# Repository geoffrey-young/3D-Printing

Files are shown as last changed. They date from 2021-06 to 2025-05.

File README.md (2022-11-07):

# random 3D printing stuff

### voron stuff

#### `artie v2.1650` stuff

* [2.4 mods, etc](./models/voron/2.4/)
* [superslicer profile and scripts](./superslicer/voron/2.4/)
* [klipper config and macros](./klipper/voron/)

#### `ernie vs.428` stuff

* [switchwire mods, etc](./models/voron/enderwire)

#### ercf stuff

* [ercf buffer, mounts, etc](./models/voron/ercf)

### ender stuff

* [cura profiles and start/end gcode](./cura/ender-3-v2/)
* [cura profile I used to print my Voron ABS parts](./cura/ender-3-v2/profiles/ABS-voron-parts.curaprofile)

### models

* [thingiverse](https://www.thingiverse.com/geoffreyyoung/designs)
* [voron printer mods](https://github.com/VoronDesign/VoronUsers/tree/master/printer_mods/geoffreyyoung)

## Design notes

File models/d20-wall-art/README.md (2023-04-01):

# D20 Wall Art

https://www.thingiverse.com/thing:4802682
**By [Geoffrey Young](https://www.thingiverse.com/geoffreyyoung)**

## Summary

### v2

Updates on 2023-04-01:

- Minor model updates, including edge tidying, bottom bevels, and a bit less plastic.
- Models are now multi-material friendly, with three parts: bottom, base, and number.  You can see the parts in the silver/black/red model picture.
- Added a first pass at a base.

The silver/black/red v2 model was printed in ABS.

### v1

Some wall art for all the DnD fans out there, including my daughter.

If you use the provided guides for spacing the end product is about 15" x 15" (38cm x 38cm). 

I used Protopasta's Iron-filled Metal Composite PLA

https://www.proto-pasta.com/collections/metal-filled/products/magnetic-iron-pla

and rusted the pieces before sanding and polishing the tops.  A light coat of spray polyurethane was added so the rust doesn't come off on finger or the wall, but I'm honestly not sure if I like the way the coating looks (they were pretty cool looking with the rust showing, while the finish makes it look kind of painted on).

3M Command strips were used for mounting.

Have fun!

#### v1 Print Settings

At full size, this required a full 1kg of iron-filled filament (that is, two 500g spools used thoughtfully to minimize spool leftovers) at the following settings:

 - Rafts      :  No                   
 - Supports   :  No                   
 - Nozzle     :  0.6mm                
 - Resolution :  0.2                
 - Line Width :  0.5                 
 - Infill     :  20% with 1 infill step
 - Bottom     :  4 layers
 - Top        :  8 layers
 - Walls      :  3

You can find instructions for rusting the iron filament here:

https://www.proto-pasta.com/blogs/how-to/17590348-improved-rusting-method-for-iron-prints

I used saturated salt in vinegar with added peroxide in a heated area over the course of a week.  After the final sanding I sprayed with just peroxide and let them sit overnight, which added a layer of rust to the sanded areas that I polished off using a cloth wheel.  ymmv :)

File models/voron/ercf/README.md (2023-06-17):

# ercf stuff...

| | |
| :--- | :--- |
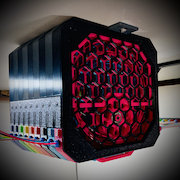
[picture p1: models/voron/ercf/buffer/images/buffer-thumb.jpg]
buffer (https://github.com/geoffrey-young/pika-filament-buffer)
| piKa filament buffer ([now a standalone repo](https://github.com/geoffrey-young/pika-filament-buffer)) |  |
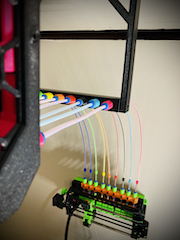
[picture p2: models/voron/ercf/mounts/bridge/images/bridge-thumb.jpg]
magnet bridge
| magnet bridge |  |
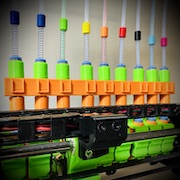
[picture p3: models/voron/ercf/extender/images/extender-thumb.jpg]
extender
| 90 degree extender |  |
| upside-down tag plates | numbers  |
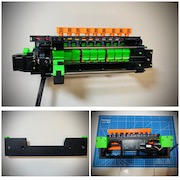
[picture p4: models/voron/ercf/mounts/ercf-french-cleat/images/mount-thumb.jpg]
mount
| french cleat mount |  |
| sb lgx mount with filament sensor<br>(no longer required with sensorless ercf) | [stl here](../stealthburner/stl/lgx/cw2/sb-lgx-cw2-ercf-v5.stl) |
| random ercf odds and ends | [here](./random/) |

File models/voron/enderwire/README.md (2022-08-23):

# `ernie vs.428`, the steathbowden enderwire

*an e3v2 switchwire conversion...*

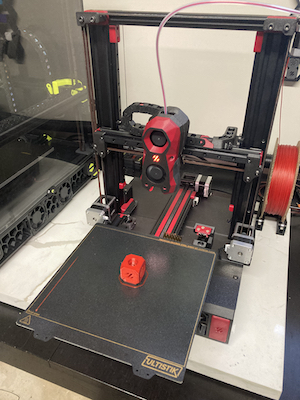
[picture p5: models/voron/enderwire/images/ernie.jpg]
ernie


### why?

this is a Voron Switchwire build for an Ender 3 v2, based on the popular [DaRk_dOg](https://github.com/boubounokefalos/Ender_SW) Switchwire mod.

the [DaRk_dOg](https://github.com/boubounokefalos/Ender_SW) mod is really fantastic, and deserves a ton of credit.  it does have some limitations, however - namely that I wanted auto z, which required a homing switch and klicky probe to be fit in somewhere.  

other than auto z, my other goal was to use as many of the original e3v2 parts as I could, in order to keep conversion costs as low as possible.

the result is `ernie vs.428` - a bowden-based stealthburner switchwire using the original e3v2 extruder, creality 4.2.2 board, and whatever other parts I could salvage from the parent e3v2.

### BOM

major BOM changes from the official [Voron Switchwire](https://vorondesign.com/voron_switchwire) and/or [DaRk_dOg](https://github.com/boubounokefalos/Ender_SW/wiki/Custom-Bom) BOM are:

| | | |
| :--- | :--- | :--- |
| **350mm rails** | 2 | provide room for the homing switch and klicky dock, and replace the dual 300mm Y rails in the DaRk_dOg mod |
| **250mm 2020 extrusions** | 2 | for use as both a bed mount and to add length for the homing switch and klicky mount.  I ordered mine from aliexpress [here](https://www.aliexpress.com/item/2255799859462895.html) |
| **m5x60 SHCS**| 2 | 8 were already needed for the frame front.  the 2 you have leftover from your pack of 10 will be used for the y idler |
| **extra GT2 belt** | 100mm | I ordered 4000mm of GT2 belt and it was more than enough, but the y axis probably needs 80-100mm more belt than a standard ender conversion.  I haven't measured the difference between the stock Switchwire (Prusa-based) BOM lengths and an ender conversion to know for sure. |
| **m4 FHCS and extrusion nuts** | 4 | to mount the bed on the extrusion.  you can probably use m3 flat heads if you have them. |
| **aliexpress [door puller](https://www.aliexpress.com/item/2255801159810332.html)** | 1 | $3 alternative to the $20 keybak from the sourcing guide, recommended on discord.  note there are 500g, 800g, and 1.1kg versions.  I have the 500g but it seems the 800g is the preferred tension.  ymmv. |
| **m5 tap** | 1 | this isn't specific to my mod - most of my stock e3v2 4040 frame was *not* tapped, so the screws for the DaRk_dOg grills had no place to go.  you'll be very happy you have this when the time comes. |

I didn't keep track of all the screws and fasteners I used, since I had an abundance sitting around, but there was nothing unique required other than the m4 screws and nuts, which I don't think are part of other standard Voron BOMs.

all the rest is from my stripped down ender...

### changes, mods, etc

there are a few categories of changes:

- alterations required where fit for my october 2020 e3v2 was a bit different than the DaRk_dOg model
- new parts needed for klicky auto z calibration
- bowden mod for stealthburner

#### replacement parts

| | |
| :--- | :--- |
| [`[a]_xz_cable_cover.stl`](stl/replacements/[a]_xz_cable_cover.stl)| a shorter cable cover so the fit against the z block is tight |
| [`[a]_y_axis_ls_mount.stl`](stl/replacements/[a]_y_axis_ls_mount.stl)| stubby y endstop mount to fit behind the 350mm rail |
| [`cover_4040_extrusion_cut_enderV2.stl`](stl/replacements/cover_4040_extrusion_cut_enderV2.stl)| the factory cutout in my frame for the electronics cable was extra large it seems |
| [`grill_rear_middle.stl`](stl/replacements/grill_rear_middle.stl)| modified to fit the factory power inlet and switch |
| [`grill_rear_right.stl`](stl/replacements/grill_rear_right.stl)| put some heatsets in the 6020 fan and use m3 screws from behind to hold it in place |
| [`keybak_gantry_anchor.stl`](stl/replacements/keybak_gantry_anchor.stl)| specific to the aliexpress door pull |
| [`keybak_idler_bracket.stl`](stl/replacements/keybak_idler_bracket.stl)| repurpose bearings, screw, and heatset from one of the ender tensioners.  there are some m4 washers you can use on the outside, but standard m5 shims work well. |
| [`keybak_mount.stl`](stl/replacements/keybak_mount.stl)| specific to the aliexpress door pull |

#### new parts

| | |
| :--- | :--- |
| [`amplifier-foot-mount.stl`](stl/new/amplifier-foot-mount.stl)| mount for standard v2.4r2/trident amplifier feet |
| [`brush-mount.stl`](stl/new/brush-mount.stl)| if you want a brush |
| [`extruder-inlet.stl`](stl/new/extruder-inlet.stl)| so you can run a 4x3mm bowden tube from the filament sensor to the extruder |
| [`extruder-knob.stl`](stl/new/extruder-knob.stl)| repurpose the large heatset from the stock extruder knob for this.  can be printed in 2 colors following the v0 miniburner process outlined [here](https://imgur.com/a/FDyniIr) |
| [`extruder-mount.stl`](stl/new/extruder-mount.stl)| mount for the stock ender extruder and stepper |
| [`klicky-mount.stl`](stl/new/klicky-mount.stl)| for auto z.  I use a m3x4mm screw in place of a magnet so I can adjust the connection strength |
| [`m4-standoff-2mm.stl`](stl/new/m4-standoff-2mm.stl)| heat and height buffer between the bed and extrusions |
| [`nozzle_probe.stl`](https://github.com/VoronDesign/Voron-2/blob/Voron2.4/STLs/Z_Endstop/nozzle_probe.stl)| use the V2.4 standard z nozzle probe assembly |
| [`stealthbowden-body.stl`](stl/new/stealthbowden-body.stl) | bowden stealthburner requires one of these two adapters from the [`Voron-Afterburner`](https://github.com/VoronDesign/Voron-Afterburner/tree/be5034975cd70203ea97729bf2bf96b6eebf6d7f/STLs/Bowden) repo:|
| [`stealthbowden-plate.stl`](stl/new/stealthbowden-plate.stl)| [BSP adapter](https://github.com/VoronDesign/Voron-Afterburner/blob/be5034975cd70203ea97729bf2bf96b6eebf6d7f/STLs/Bowden/bowden_single_bsp_adapter.stl) or [TL collet](https://github.com/VoronDesign/Voron-Afterburner/blob/be5034975cd70203ea97729bf2bf96b6eebf6d7f/STLs/Bowden/bowden_single_tl_collet_adapter.stl)  |
| [`tl-filament-sensor-bracket.stl`](stl/new/tl-filament-sensor-bracket.stl)| trianglelabs filament runout bracket |
| [`wago-bed-mount.stl`](stl/new/wago-bed-mount.stl)| holds two wago 221-413 lever-nuts for the bed heater wires |
| [`xy_chain_end-inner.stl`](stl/new/xy_chain_end-inner.stl) | 2 hole chain end for the x axis extrusion mount point.  lets you print some bling, plus if you use it you know your chain is facing the right direction :) |
| [`y-axis-350mm-extension.stl`](stl/new/y-axis-350mm-extension.stl)| add-on to the 4040 y frame to give room for the 350mm rails.  use two m5x60 for the bottom (y idler) holes and two m5x45 or m5x50 for the hidden (upper) holes |
| [`y-bed-chain-extension-generic.stl`](stl/new/y-bed-chain-extension-generic.stl)| the longer y movement needs longer bed chains.  you can either use this extension, or take 3 links from the x chain (since it's too long anyway) |
| [`y-endstop-bed-extension.stl`](stl/new/y-endstop-bed-extension.stl)| needed to hit the new y endstop position |

#### other stuff

| | |
| :--- | :--- |
| [v-slot covers](https://www.thingiverse.com/thing:4681157)| I like these from thingiverse best |
| [2020 endcap](stl/new/2020-endcap.stl)| 2-sided mod of [this from thingiverse](https://www.thingiverse.com/thing:813368) |

### build notes, etc

the [DaRk_dOg](https://github.com/boubounokefalos/Ender_SW) mod makes the auto z mods pretty simple - it's really just another (slightly modified) 4040 extension block, longer y rails, and a few mounts.  the biggest drawback I've noticed so far is that the way I set it up you lose the adjustment screws so you need to live with a fixed bed.  klicky takes care of that for the most part (my first, untuned mesh had a 0.9mm deviation - not great, but...).  however, I think that could be worked around by just a bit more modding of the bed carriage.  stay tuned for v2 :)

here are some random build notes and other thoughts.  I'll keep adding details as I think of them...

- I don't think gear pullers are required - my e3v2 x and y motor gears aligned perfectly with the DaRk_dOg x and z assemblies.
- not all of the extrusion holes are tapped, so that m5 tap really will come in handy
- more to come...

### wiring

the wiring for the creality 4.2.2 board is well documented, but I'll eventually post my klipper config.

as for the stealthburner led and klicky wiring, both can be serviced by the bltouch port:

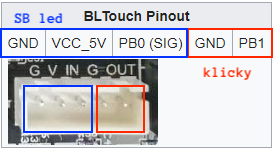
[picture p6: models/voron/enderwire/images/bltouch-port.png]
stealthburner led and klicky ports


### pictures

first print off the block - no input shaper, pressure advance, etc.  not perfect, but not bad :)

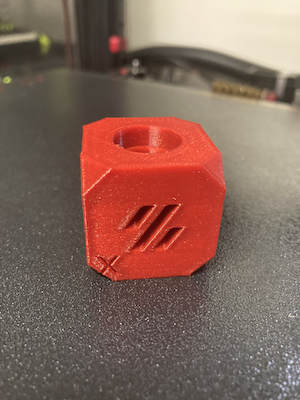
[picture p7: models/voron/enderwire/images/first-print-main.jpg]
first print


some others for reference...

| | | |
| :--- | :--- | :--- |
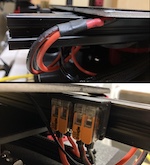
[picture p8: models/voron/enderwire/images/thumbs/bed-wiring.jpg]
bed wiring
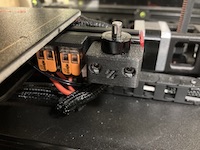
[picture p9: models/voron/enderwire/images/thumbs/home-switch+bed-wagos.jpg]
home switch and bed wagos
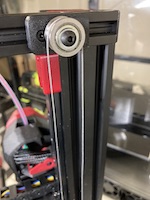
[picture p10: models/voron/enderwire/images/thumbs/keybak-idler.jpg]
keybak idler
|  |  |  |
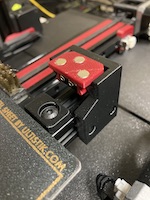
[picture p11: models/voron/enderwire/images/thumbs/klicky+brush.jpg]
klicky and brush mounts
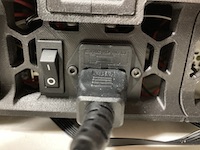
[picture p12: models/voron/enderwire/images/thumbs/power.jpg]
power inlet
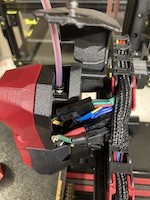
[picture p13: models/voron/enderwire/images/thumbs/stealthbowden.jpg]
stealthbowden
|  |  |  |
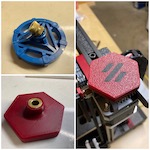
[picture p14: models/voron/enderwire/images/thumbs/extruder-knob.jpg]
extruder knob
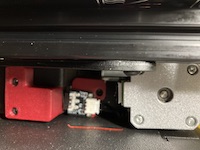
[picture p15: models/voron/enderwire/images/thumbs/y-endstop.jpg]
y endstop and bed extension
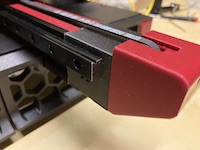
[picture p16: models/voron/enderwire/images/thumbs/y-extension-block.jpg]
y extension block
|  |  |  |
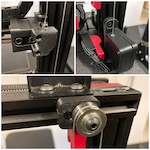
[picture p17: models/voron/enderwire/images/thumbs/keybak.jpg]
keybak
|  | |

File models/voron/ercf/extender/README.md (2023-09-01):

# ercf extender

now in 9.5mm and 10mm magnet versions.  please see [a note on magnets](https://github.com/geoffrey-young/pika-filament-buffer#a-note-on-magnets)

| | |
| :---: | :---: |
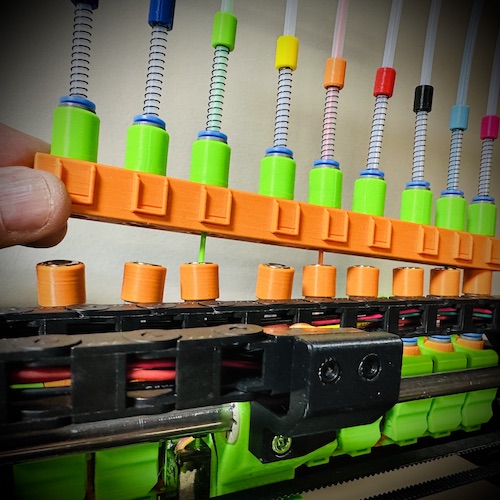
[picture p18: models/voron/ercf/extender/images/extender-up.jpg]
ercf 90 degree extender up
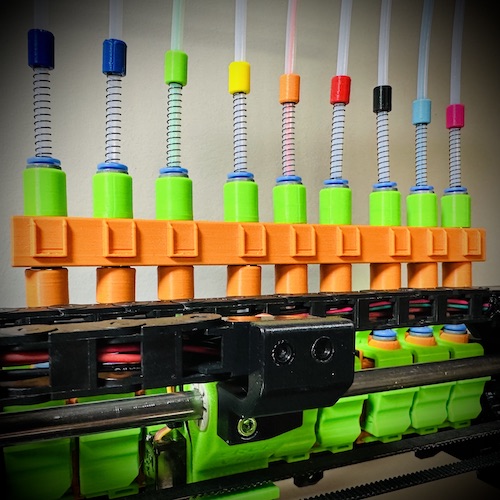
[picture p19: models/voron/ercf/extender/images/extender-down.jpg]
ercf 90 degree extender
|  |  |

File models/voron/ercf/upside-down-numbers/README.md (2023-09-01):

# ercf upside-down number tags

helpful if you happen to mount things in odd ways.  multi-material ready.

in [anonymous pro](https://www.marksimonson.com/fonts/view/anonymous-pro).  obviously.

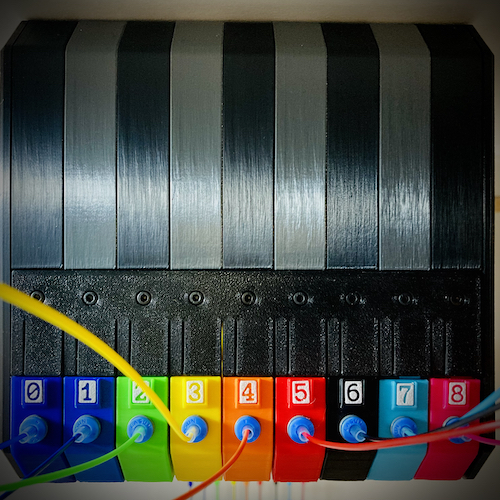
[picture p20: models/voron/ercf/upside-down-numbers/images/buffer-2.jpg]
upside down tag plates


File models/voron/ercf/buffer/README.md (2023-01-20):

# I've moved!

you can find the standalone repo [here](https://github.com/geoffrey-young/filament-buffer)

enjoy.

| | |
| :---: | :---: |
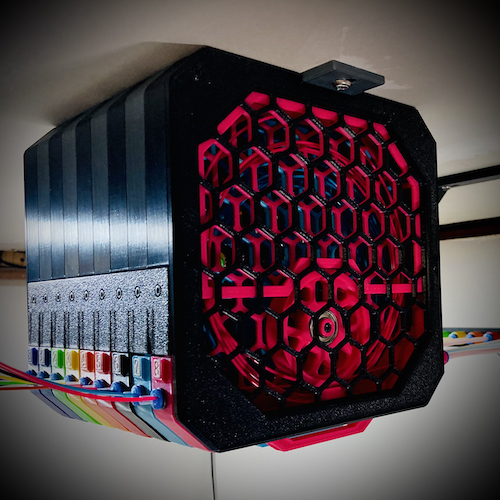
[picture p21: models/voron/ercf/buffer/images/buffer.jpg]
buffer
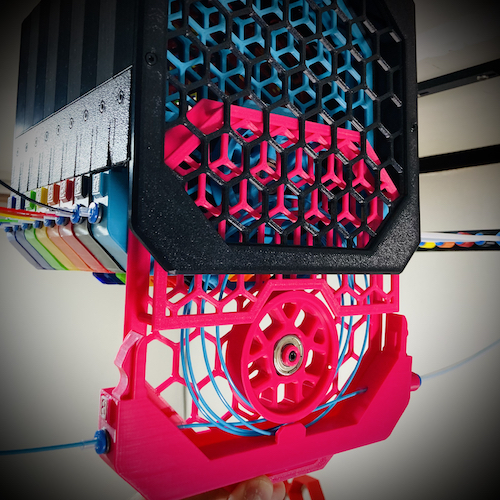
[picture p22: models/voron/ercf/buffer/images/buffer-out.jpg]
buffer out
|  |  |

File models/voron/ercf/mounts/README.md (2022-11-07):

# ercf mounts...

| | |
| :--- | :--- |
| magnet bridge | magnet bridge |
| french cleat mount | mount |

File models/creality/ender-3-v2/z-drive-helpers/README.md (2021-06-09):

# Z-Axis Motor Mount and Leveling Kit for Ender 3 V2

https://www.thingiverse.com/thing:4789170
**By [Geoffrey Young](https://www.thingiverse.com/geoffreyyoung)**

### Summary

I purchased a dual z-axis upgrade kit and the product had some tolerance issues - the z-axis mount wasn't square and the stator housing exceeded the width of the end caps.  The net result was a complete inability to mount the stepper motor square and align things properly.

This is an entire kit of mounts and tools to remedy those issues, including:

  o A simple z-axis motor mount with a bit more clearance so that the motor doesn't quite touch the z-axis rails

  o A set of adjustable leveling brackets for the other side of the stepper motor

  o A combined mount + leveling bracket (as an alternative to using separate parts)

  o Some simple washers to account for the distance difference in the x-axis roller bracket assembly

  o An adjustable spacer measuring jig for the z-axis rod lead screw

  o A simple x-axis rail level

The stepper motor leveling brackets require some hardware:

  o 2 M3x6 screws
  o 2 M3x16 screws
  o 2 M3x6x10 threaded inserts

You can see in the photos how it's all set up, but it's pretty self explanatory.  You can use the mount+bracket combo if you're adding a new stepper motor, or just add the outer leveling bracket if you want to use existing mounts.

The spacer jig is really handy, and I use the x-axis level all the time.

I'm particularly fond of the bottom bracket, which I consistenly refer to as the TRON Recognizer.

I used https://www.thingiverse.com/thing:4699747 as the base for the design, but pretty much tore it apart.  The concept for the leveling brackets were inspired by https://www.thingiverse.com/thing:4073953, which is a great idea but had too many nuts and bolts for me :)

Anyway, all these things helped me tune the upgrade kit, and I ended up applying it to the original setup as well.  Smooth as silk now.

As always, ymmv.

### Attributions

[Ender 3 / Pro / V2 Z axis motor mount](https://www.thingiverse.com/thing:4699747) by [mknet](https://www.thingiverse.com/mknet)

[Ender 3 Z-Axis Stepper Mount / Adjusting Aid](https://www.thingiverse.com/thing:4073953) by [LordHotEnd](https://www.thingiverse.com/LordHotEnd)

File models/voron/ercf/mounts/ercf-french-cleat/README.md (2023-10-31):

# ercf french cleat wall mount

frame based on the ercf [mounting frame usermod](https://github.com/EtteGit/EnragedRabbitProject/tree/main/usermods/Mounting%20Frame)

currently compatible with the following board mounts:

 * [ercf easy board mount](https://github.com/EtteGit/EnragedRabbitProject/blob/main/Carrot_Feeder/Stls/Supports/Adjustable%20mount/Option/ERCF_Easy_Brd_Bracket_Mount.stl)
 * [btt mmb mount](https://www.printables.com/model/611961-btt-mmb-can-sideway-mount)

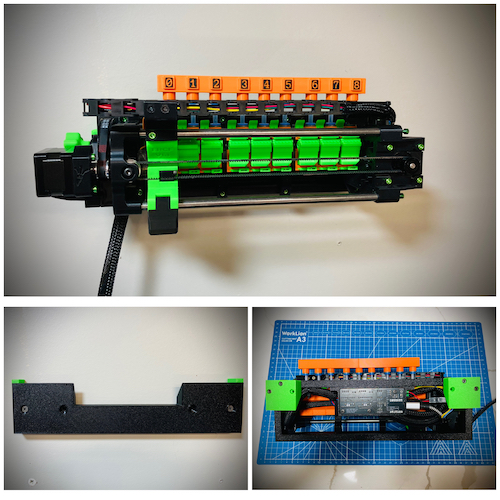
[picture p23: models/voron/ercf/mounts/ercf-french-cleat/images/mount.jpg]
french cleat mount


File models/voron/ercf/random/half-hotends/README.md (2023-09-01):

## half hotend models...

useful models for helping tip tuning

- half dragon: [half-dragon-multicolor.stl](half-dragon-multicolor.stl)
- half rapido: [half-rapido-multicolor.stl](half-rapido-multicolor.stl)

if I ever use a different hotend I'll whip one of those up, too.  for now, this is all (so please don't ask :)

see this discord post for a video of the model in action:

https://discord.com/channels/460117602945990666/909743915475816458/1069831340851200122

## howto

use split to parts... in superslicer, at least

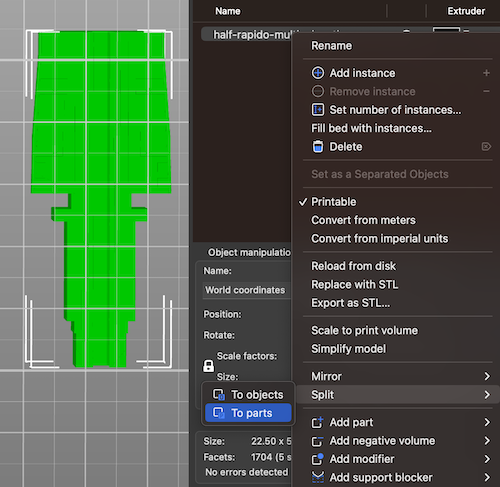
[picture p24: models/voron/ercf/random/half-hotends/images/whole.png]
whole

split

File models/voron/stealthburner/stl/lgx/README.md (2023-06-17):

# lgx stealthburner stuff...

now confirmed working with the official sb release!

### stuff:

| | | |
| :--- | :--- | :--- |
| cw1 mount | [front](cw1/sb-lgx-front-cw1.stl), [rear](cw1/sb-lgx-rear-cw1.stl) | |
| cw2 mount | [all in one](cw2/sb-lgx-cw2-v5.stl) | |
| cable chain anchor | [here](sb-lgx-anchor.stl) | |
| cover | [here](sb-lgx-cover.stl) | I use a few plastic washers as spacers on the mount screw to keep it tight - the fit isn't snug on purpose, since it really depends on how much stuff you stuff in there... |
| ercf toolhead sensor mount | [here](cw2/sb-lgx-cw2-ercf-v5.stl) | works well, and even better with a legit N52 magnet like you can find [here](https://deepfriedhero.in/products/n52-6x3mm-round-black-nickel-magnets).  I didn't port over the retaning screw - the lgx holds a properly heatshrink-applied hall effect sensor in snugly.  there's space for a bit of hot glue for extra holding (which is what I do) |



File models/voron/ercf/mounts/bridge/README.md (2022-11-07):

# magnet bridge

magnet bridge

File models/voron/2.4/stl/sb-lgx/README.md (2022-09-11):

[I've moved...](../../../stealthburner/stl/lgx/README.md )

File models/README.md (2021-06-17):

# 3D Printing Models

Here you can find some of the models I've designed that may or may not be of interest.

---

| | |
| :--- | :--- |
| [`creality`](creality/) | random mods, remixes, and bling for my ender 3 v2 |
| [`voron`](voron/2.4/) | random mods, remixes, and bling for my voron 2.4 build |
| [`d20 wall art`](d20-wall-art/) | one of the designs I'm most proud of |
---

More designs and remixes can be found on [my Thingiverse page](https://www.thingiverse.com/geoffreyyoung/designs)

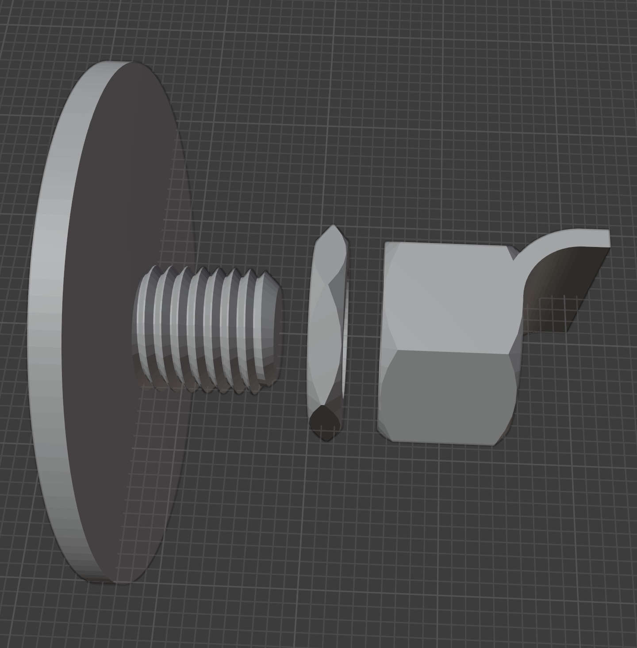
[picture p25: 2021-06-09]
models/creality/ender-3-v2/z-drive-helpers/images/jig-blend.jpg

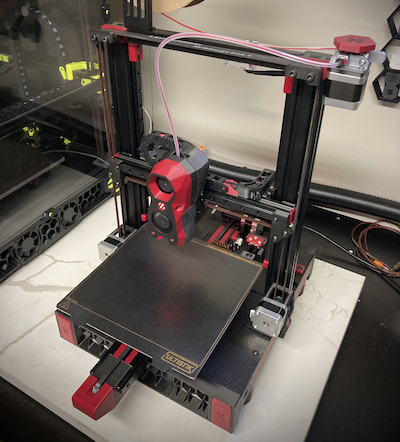
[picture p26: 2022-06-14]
models/voron/enderwire/images/ernie-main.jpg

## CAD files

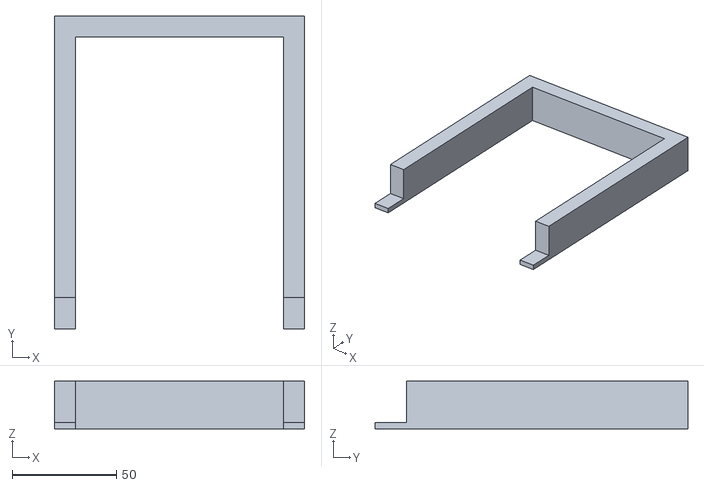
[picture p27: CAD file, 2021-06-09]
models/creality/ender-3-v2/z-drive-helpers/stl/level.stl
120.0 x 150.0 x 23.0

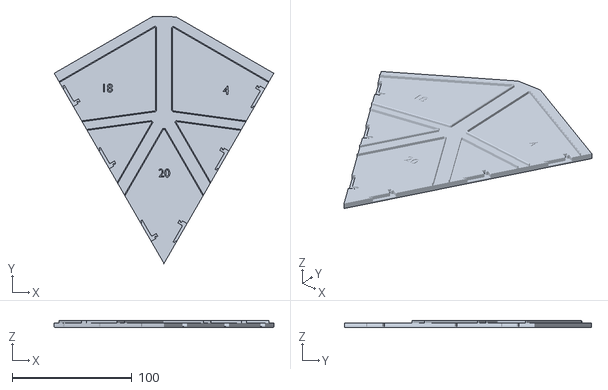
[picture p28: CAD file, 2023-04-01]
models/d20-wall-art/v2/base/v2-base-1.stl
183.5 x 206.3 x 6.00

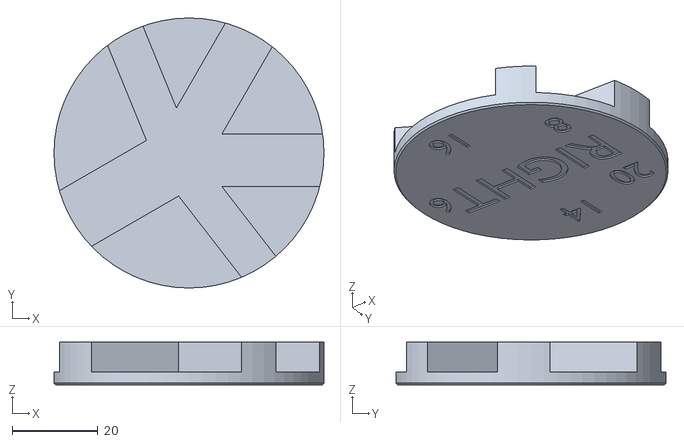
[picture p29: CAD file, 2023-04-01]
models/d20-wall-art/v2/guides/v2-right-guide.stl
63.0 x 63.0 x 10.0

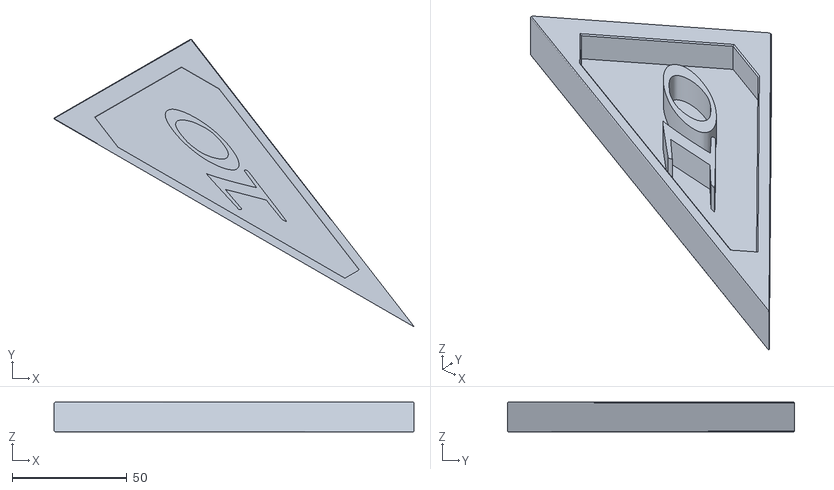
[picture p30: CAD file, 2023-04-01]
models/d20-wall-art/v2/v2-10.stl
157.2 x 125.5 x 13.0

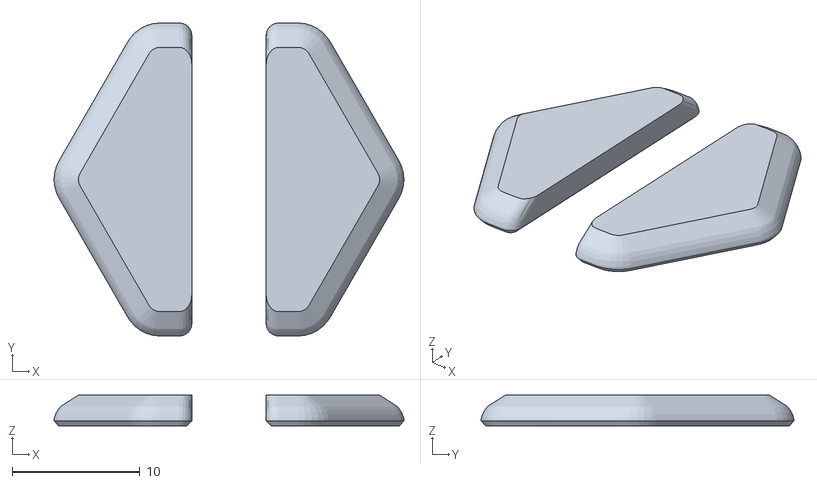
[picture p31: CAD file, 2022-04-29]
models/voron/2.4/stl/bling/z_drive_inserts.stl
27.4 x 24.5 x 2.42

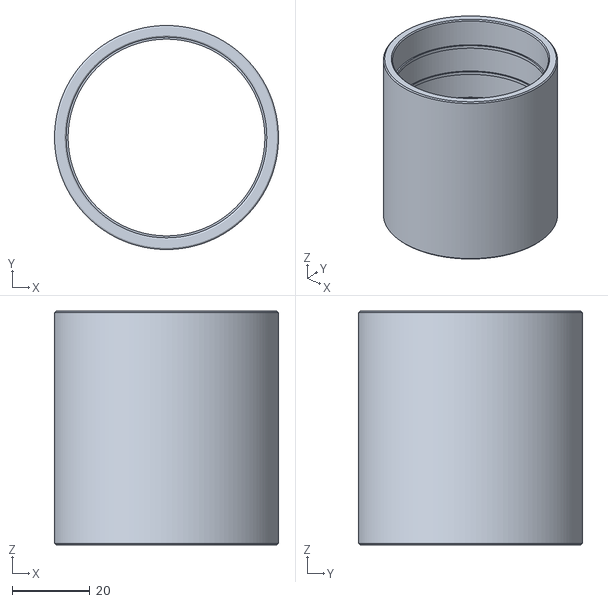
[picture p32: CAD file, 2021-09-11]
models/voron/2.4/stl/bofa/tpu_hose_coupling.stl
57.5 x 57.5 x 60.0

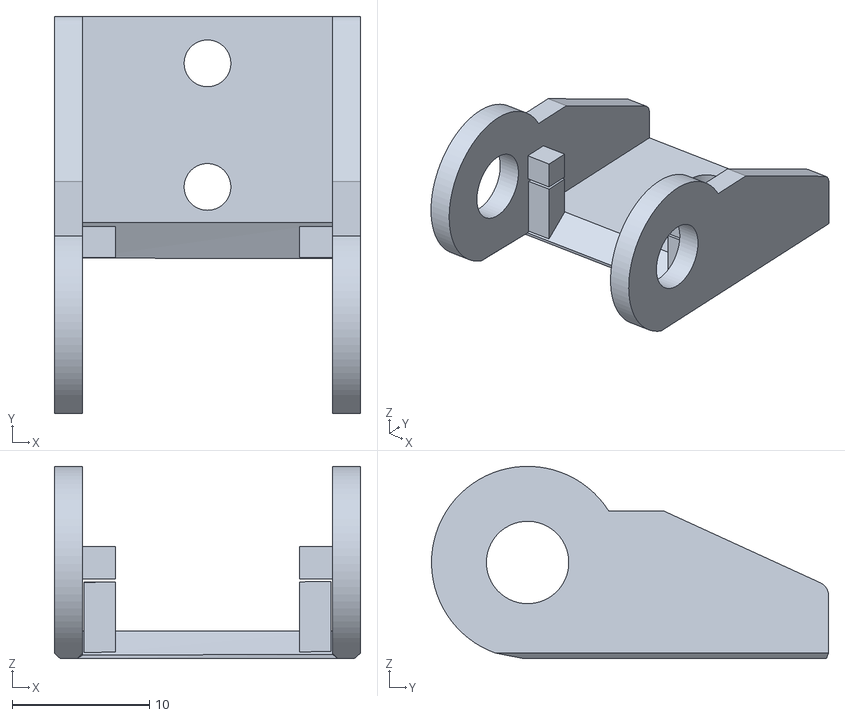
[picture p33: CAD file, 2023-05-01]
models/voron/2.4/stl/chains/z_chain_end-outer-locked.stl
22.3 x 28.9 x 14.0

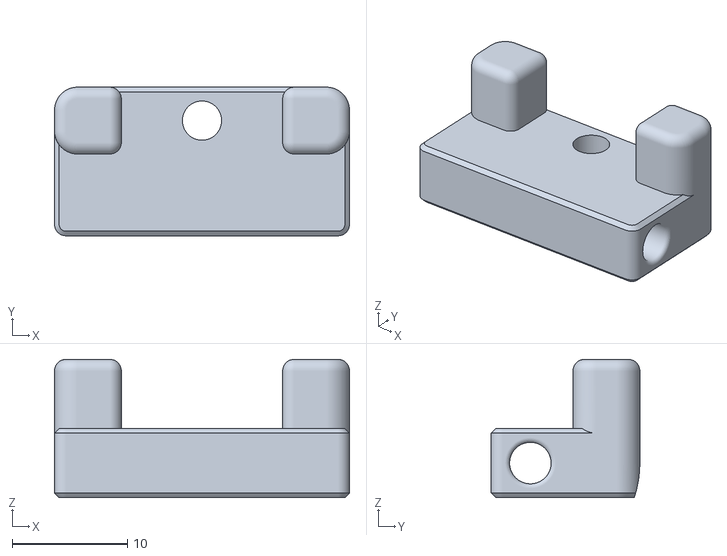
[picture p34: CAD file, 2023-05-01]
models/voron/2.4/stl/doors/hinge_block.stl
25.6 x 12.9 x 12.0

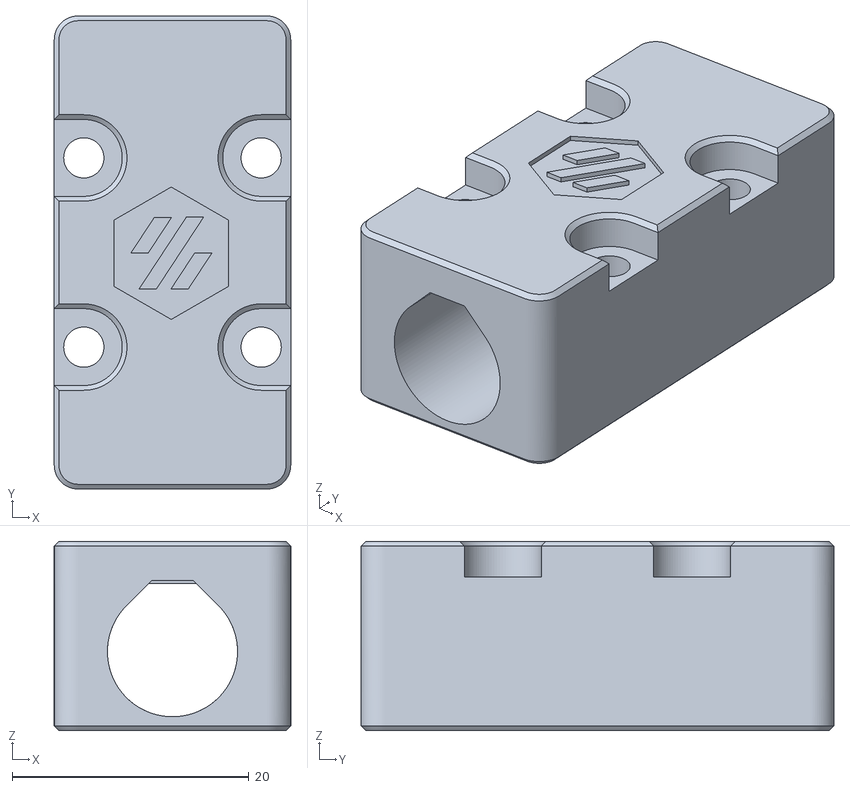
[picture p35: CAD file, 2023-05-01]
models/voron/2.4/stl/ge5c/ge5c_4_0mm.stl
20.0 x 40.0 x 16.0

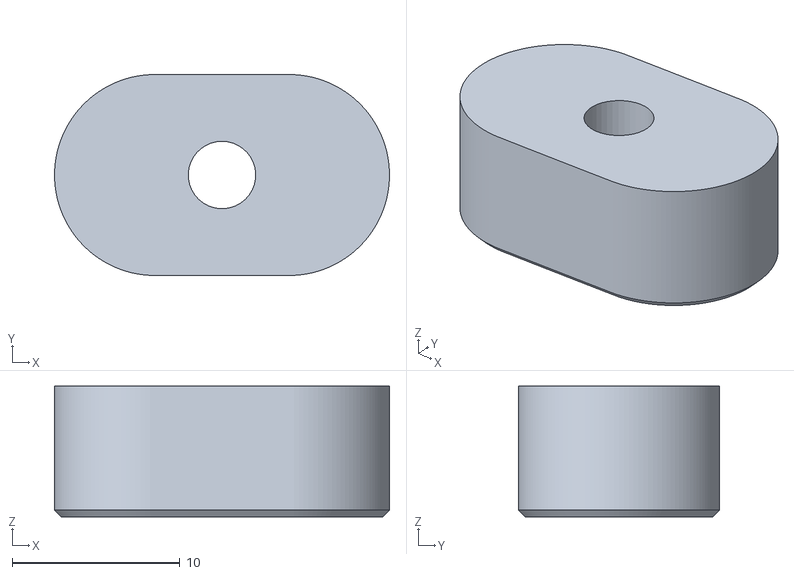
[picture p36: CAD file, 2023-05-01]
models/voron/2.4/stl/other/m4_bed_standoff.stl
20.0 x 12.0 x 7.80

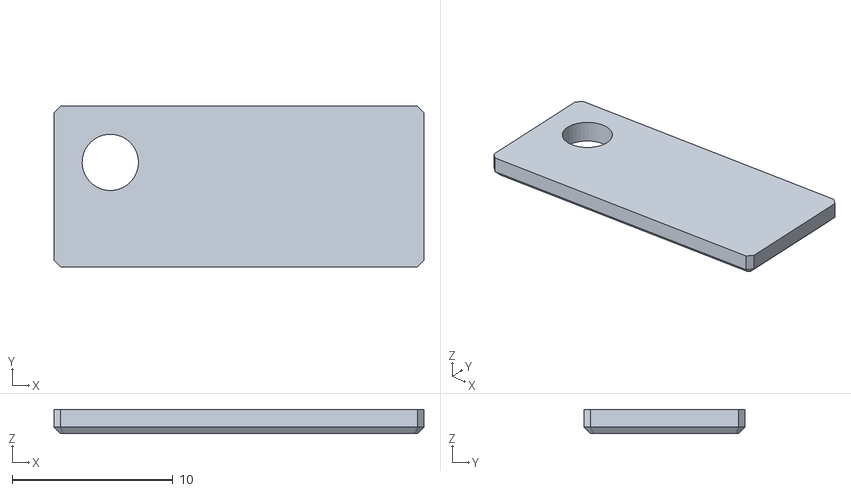
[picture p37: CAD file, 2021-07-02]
models/voron/2.4/stl/sb-lgx/lgx-gear-cover.stl
23.0 x 10.0 x 1.50

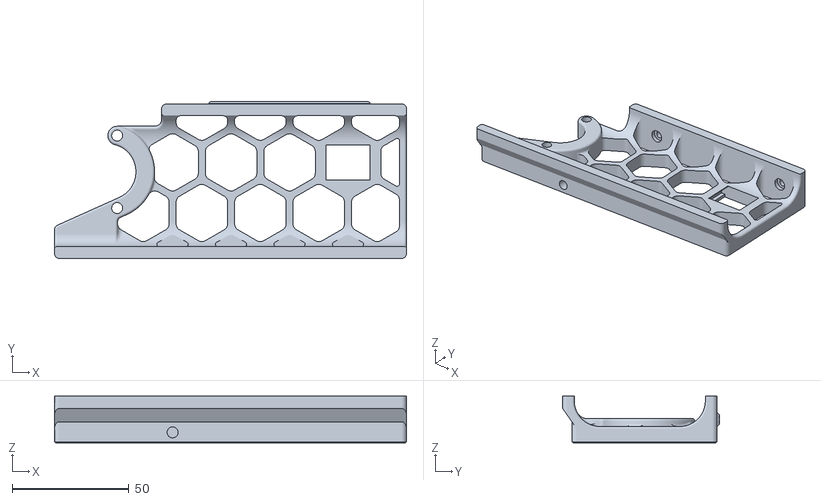
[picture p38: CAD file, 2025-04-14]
models/voron/2.4/stl/skirts/left-front.stl
150.5 x 67.0 x 20.0

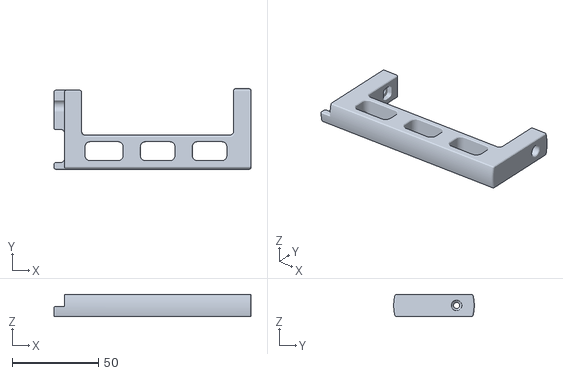
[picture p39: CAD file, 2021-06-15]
models/voron/2.4/stl/spool-holder/spool_holder.stl
114.0 x 46.7 x 13.0

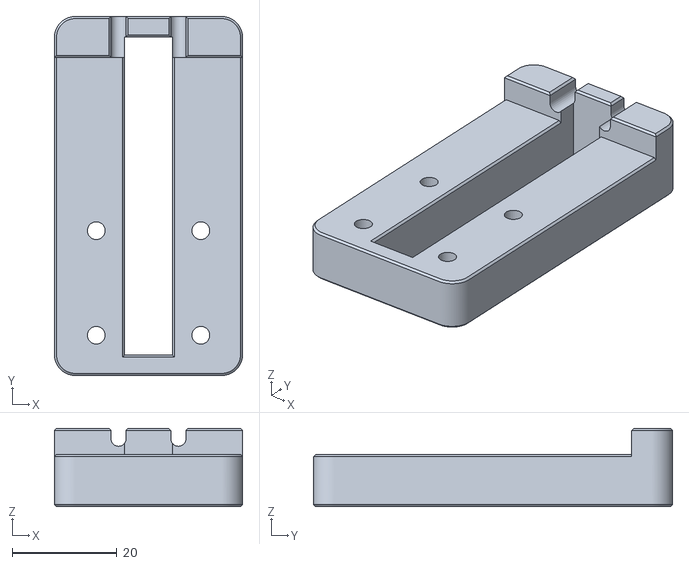
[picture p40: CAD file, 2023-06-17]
models/voron/2.4/stl/tap/tap-mgn9-rail-guide.stl
36.0 x 68.7 x 15.0

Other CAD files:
models/voron/enderwire/stl/new/y-axis-adxl-mount.stl
models/voron/enderwire/stl/replacements/keybak_mount.stl
models/voron/ercf/extender/stl/[a]_10mm-ecas-to-magnet-end_xN.stl
models/voron/ercf/mounts/bridge/stl/bridge-mount-9.stl
models/creality/ender-3-v2/z-drive-helpers/stl/bottom-bracket.stl
models/creality/ender-3-v2/z-drive-helpers/stl/jig-bolt.stl
models/creality/ender-3-v2/z-drive-helpers/stl/jig-guide.stl
models/creality/ender-3-v2/z-drive-helpers/stl/jig-lock-nut.stl
models/creality/ender-3-v2/z-drive-helpers/stl/top-bracket.stl
models/creality/ender-3-v2/z-drive-helpers/stl/washer-1_5mm.stl
models/creality/ender-3-v2/z-drive-helpers/stl/washer-1mm.stl
models/creality/ender-3-v2/z-drive-helpers/stl/washer-2mm.stl
models/creality/ender-3-v2/z-drive-helpers/stl/z-axis-mount-with-bracket.stl
models/creality/ender-3-v2/z-drive-helpers/stl/z-axis-mount.stl
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

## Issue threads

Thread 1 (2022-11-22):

Excellent design!

nigelpjames, 2022-11-22:
Awesome work.  I have long bowden tubes as well and was designing a buffer that could handle 1100mm of filament without needing a wheel and could be loaded quickly.  Your adaptation and design works really well and have shelved my project after testing your cart design this week.  My thanks and gratitude.

The only change I'm planing at this stage is to cut clear acrylic sheet for the buffer ends to limit potential moisture issues and airflow around spooled ABS. Probably wont make a material difference but easy to do.

Sourcing m2 self tappers with hex or phillips head screws with small heads quickly where I live is proving a little difficult.
buffer-top-magnet+magnet.stl needs to be printed vertical to avoid supports for clip & slot number.  Initial overhang is > 45 degrees on rounded radius and would be easier to print if it was a constant 45 for this particular part.

Regards

nigelpjames, 2022-11-24:
Disregard comment re vertical orientation...now printing buffer-top_magnet+magnet.stl on side with minimum supports required.  was concerned about number slot and being difficult able to side the number in if supports were used but came off cleaner than expected.

geoffrey-young, 2023-01-10:
glad you found it useful :)

I've updated the models so they're all already in the proper orientation, and added some printing notes as well.

Closed 2023-01-10.

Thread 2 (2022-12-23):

Could you upload STEP or OBJ files

GitjoPowershell, 2022-12-23:
Hi,
First I would like to thank you for your design that i use since a while, however i recently moved to TAP on my voron V2 and I found the following issues on the TAP using sb-lgx-cw2-v5
1: the front hole for the LGX screw miss some clearance (the screw head should enter into the hole)
2: the bottom part where the piece enter into the carriage miss a bit of clearance, i had to cut it with an exacto to make it fit

does it sounds possible that you upload the STEP or Obj files of your model to allow some tuning and make it compliant with TAP ?

Happy endings and once again thanks for your work !

geoffrey-young, 2023-01-09:
hi :)

with respect to the lgx screw
clearance, m3 x 27 low profile screws are impossible to find, so the lack of recess actually allows us all to use standard m3x30 screws for mounting to the x carriage.  there
is plenty of room in the stealtburner housing for the screw heads, so we all get a little quality of life improvement :)

as for issue 2, I suspect that has more
to do with your overhang slicer settings -
I’ve printed it at least a dozen times and never had a fit issue.

I use blender, so all I have to offer is stl files, unfortunately.  otherwise I’d happily offer up full cad.

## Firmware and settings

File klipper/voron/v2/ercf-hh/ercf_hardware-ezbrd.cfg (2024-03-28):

[mcu ercf]
serial: /dev/serial/by-id/usb-Klipper_samd21g18a_486A10FC3052575020312E37300515FF-if00

[tmc2209 manual_stepper gear_stepper]
uart_pin: ercf:PA8
uart_address: 0
interpolate: True
run_current: 0.5
hold_current: 0.1
sense_resistor: 0.110
stealthchop_threshold: 0

[manual_stepper gear_stepper]
step_pin: ercf:PA4
dir_pin: ercf:PA10
enable_pin: !ercf:PA2
rotation_distance: 23.24592478
gear_ratio: 80:20
microsteps: 16
full_steps_per_rotation: 200
velocity: 100
accel: 400
endstop_pin: ^ercf:PB9

[tmc2209 manual_stepper selector_stepper]
uart_pin: ercf:PA8
uart_address: 1
run_current: 0.5
hold_current: 0.3
interpolate: True
sense_resistor: 0.110
stealthchop_threshold: 0
diag_pin: ^ercf:PA7
driver_SGTHRS: 75

[manual_stepper selector_stepper]
step_pin: ercf:PA9
dir_pin: ercf:PB8
enable_pin: !ercf:PA11        
rotation_distance: 40
microsteps: 16
full_steps_per_rotation: 200
velocity: 500
accel: 1000
endstop_pin: tmc2209_selector_stepper:virtual_endstop

[ercf_servo ercf_servo]
pin: ercf:PA5
maximum_servo_angle: 180
minimum_pulse_width: 0.00085
maximum_pulse_width: 0.00215

[ercf_encoder ercf_encoder]
encoder_pin: ^ercf:PA6
encoder_resolution: 1.387925
#encoder_resolution: 1.367989
extruder: extruder
desired_headroom: 5.0
average_samples: 6

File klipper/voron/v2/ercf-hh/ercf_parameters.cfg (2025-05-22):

[ercf]

home_position_to_nozzle: 65.0
#extruder_to_nozzle: 0
#sensor_to_nozzle: 0


#colorselector:  3.7, 24.2, 44.5, 70.5, 91.5, 111.9, 137.5, 158.4, 179.2
colorselector:  2.6, 22.2, 42.9, 68.5, 89.5, 109.9, 135.5, 156.4, 177.2
bypass_selector: 58.5


log_level: 1
logfile_level: 4
log_statistics: 1
log_visual: 0
startup_status: 1


long_moves_speed: 150
short_moves_speed: 50 


servo_up_angle: 25
servo_down_angle: 105


calibration_bowden_length: 1100
num_moves: 1
apply_bowden_correction: 1


toolhead_homing_max: 40
toolhead_homing_step: 1.0

extruder_homing_max: 50
extruder_homing_step: 1.0
extruder_homing_current: 40
extruder_form_tip_current: 100


sync_load_length: 10
sync_unload_length: 10


sensorless_selector: 1
enable_clog_detection: 2
enable_endless_spool: 0


persistence_level: 0


parking_distance: 21   # default 23, usually 20


min_temp_extruder: 224
#min_temp_extruder: -1

timeout_pause: 72000
disable_heater: 600
unload_buffer: 60
load_encoder_retries: 2
load_bowden_tolerance: 8.0
delay_servo_release: 2.0
z_hop_height: 5
z_hop_speed: 15
sync_load_speed: 10
sync_unload_speed: 10
nozzle_load_speed: 15
nozzle_unload_speed: 20
servo_duration: 0.2
ignore_extruder_load_error: 0
homing_method: 0

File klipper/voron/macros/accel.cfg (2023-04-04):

[include util/PRINT_TYPE_ACCEL.cfg]

# call this as gcode_macro from PRINT_START or as delayed_gcode for setting once on printer start

[gcode_macro CONFIGURE_SLOW_PRINT_TYPE_ACCEL]
description: SET_VELOCITY_LIMIT ACCEL=1500 for print moves
gcode:
  SET_ACCEL_FOR_TYPE TYPE=Default                  VALUE=1500

  # first layer stuff
  SET_ACCEL_FOR_TYPE TYPE=FirstLayer               VALUE=1500
  SET_ACCEL_FOR_TYPE TYPE=Skirt                    VALUE=3000

  # visible types
  SET_ACCEL_FOR_TYPE TYPE=ExternalPerimeter        VALUE=1500
  SET_ACCEL_FOR_TYPE TYPE=ThinWall                 VALUE=1500
  SET_ACCEL_FOR_TYPE TYPE=Perimeter                VALUE=1500
  SET_ACCEL_FOR_TYPE TYPE=OverhangPerimeter        VALUE=1500
  SET_ACCEL_FOR_TYPE TYPE=TopSolidInfill           VALUE=1500
  SET_ACCEL_FOR_TYPE TYPE=GapFill                  VALUE=1500

  # invisible fill
  SET_ACCEL_FOR_TYPE TYPE=BridgeInfill             VALUE=3000
  SET_ACCEL_FOR_TYPE TYPE=SolidInfill              VALUE=7000
  SET_ACCEL_FOR_TYPE TYPE=InternalInfill           VALUE=7000

  # supports, etc
  SET_ACCEL_FOR_TYPE TYPE=SupportMaterial          VALUE=3000
  SET_ACCEL_FOR_TYPE TYPE=SupportMaterialInterface VALUE=3000
  SET_ACCEL_FOR_TYPE TYPE=WipeTower                VALUE=3000

  # inbetween travel moves
  SET_ACCEL_FOR_TYPE TYPE=Travel                   VALUE=7000 

  M118 SLOW accel, default 1500


[gcode_macro CONFIGURE_FINE_PRINT_TYPE_ACCEL]
description: slow visible, really fast non-visible accels
gcode:
  SET_ACCEL_FOR_TYPE TYPE=Default                  VALUE=1000

  # first layer stuff
  SET_ACCEL_FOR_TYPE TYPE=FirstLayer               VALUE=1000
  SET_ACCEL_FOR_TYPE TYPE=Skirt                    VALUE=7000

  # visible types
  SET_ACCEL_FOR_TYPE TYPE=ExternalPerimeter        VALUE=1000
  SET_ACCEL_FOR_TYPE TYPE=ThinWall                 VALUE=1000
  SET_ACCEL_FOR_TYPE TYPE=Perimeter                VALUE=1000
  SET_ACCEL_FOR_TYPE TYPE=OverhangPerimeter        VALUE=1000
  SET_ACCEL_FOR_TYPE TYPE=TopSolidInfill           VALUE=1000
  SET_ACCEL_FOR_TYPE TYPE=GapFill                  VALUE=1000

  # invisible fill
  SET_ACCEL_FOR_TYPE TYPE=BridgeInfill             VALUE=7000
  SET_ACCEL_FOR_TYPE TYPE=SolidInfill              VALUE=7000
  SET_ACCEL_FOR_TYPE TYPE=InternalInfill           VALUE=7000

  # supports, etc
  SET_ACCEL_FOR_TYPE TYPE=SupportMaterial          VALUE=7000
  SET_ACCEL_FOR_TYPE TYPE=SupportMaterialInterface VALUE=7000
  SET_ACCEL_FOR_TYPE TYPE=WipeTower                VALUE=7000

  # inbetween travel moves
  SET_ACCEL_FOR_TYPE TYPE=Travel                   VALUE=7000

  M118 FINE accel, visible 1000, invisible 7000


[gcode_macro CONFIGURE_SUPERFINE_PRINT_TYPE_ACCEL]
description: slow visible, really fast non-visible accels
gcode:
  SET_ACCEL_FOR_TYPE TYPE=Default                  VALUE=1000

  # first layer stuff
  SET_ACCEL_FOR_TYPE TYPE=FirstLayer               VALUE=1000
  SET_ACCEL_FOR_TYPE TYPE=Skirt                    VALUE=7000

  # visible types
  SET_ACCEL_FOR_TYPE TYPE=ExternalPerimeter        VALUE=500
  SET_ACCEL_FOR_TYPE TYPE=ThinWall                 VALUE=1000
  SET_ACCEL_FOR_TYPE TYPE=Perimeter                VALUE=1000
  SET_ACCEL_FOR_TYPE TYPE=OverhangPerimeter        VALUE=500
  SET_ACCEL_FOR_TYPE TYPE=TopSolidInfill           VALUE=500
  SET_ACCEL_FOR_TYPE TYPE=GapFill                  VALUE=1000

  # invisible fill
  SET_ACCEL_FOR_TYPE TYPE=BridgeInfill             VALUE=7000
  SET_ACCEL_FOR_TYPE TYPE=SolidInfill              VALUE=7000
  SET_ACCEL_FOR_TYPE TYPE=InternalInfill           VALUE=7000

  # supports, etc
  SET_ACCEL_FOR_TYPE TYPE=SupportMaterial          VALUE=7000
  SET_ACCEL_FOR_TYPE TYPE=SupportMaterialInterface VALUE=7000
  SET_ACCEL_FOR_TYPE TYPE=WipeTower                VALUE=7000

  # inbetween travel moves
  SET_ACCEL_FOR_TYPE TYPE=Travel                   VALUE=7000

  M118 SUPERFINE accel, outer 500, visible 1000, invisible 7000


[gcode_macro CONFIGURE_FAST_PRINT_TYPE_ACCEL]
description: SET_VELOCITY_LIMIT ACCEL=3000 for print moves
gcode:
  SET_ACCEL_FOR_TYPE TYPE=Default                  VALUE=3000

  SET_ACCEL_FOR_TYPE TYPE=FirstLayer               VALUE=3000
  SET_ACCEL_FOR_TYPE TYPE=Skirt                    VALUE=3000

  SET_ACCEL_FOR_TYPE TYPE=ExternalPerimeter        VALUE=3000
  SET_ACCEL_FOR_TYPE TYPE=ThinWall                 VALUE=3000
  SET_ACCEL_FOR_TYPE TYPE=Perimeter                VALUE=3000
  SET_ACCEL_FOR_TYPE TYPE=OverhangPerimeter        VALUE=3000
  SET_ACCEL_FOR_TYPE TYPE=TopSolidInfill           VALUE=3000
  SET_ACCEL_FOR_TYPE TYPE=GapFill                  VALUE=3000

  SET_ACCEL_FOR_TYPE TYPE=BridgeInfill             VALUE=5000
  SET_ACCEL_FOR_TYPE TYPE=SolidInfill              VALUE=7000
  SET_ACCEL_FOR_TYPE TYPE=InternalInfill           VALUE=7000

  SET_ACCEL_FOR_TYPE TYPE=SupportMaterial          VALUE=7000
  SET_ACCEL_FOR_TYPE TYPE=SupportMaterialInterface VALUE=7000
  SET_ACCEL_FOR_TYPE TYPE=WipeTower                VALUE=7000

  SET_ACCEL_FOR_TYPE TYPE=Travel                   VALUE=7000 

  M118 FAST accel, default 3000


[gcode_macro CONFIGURE_SUPER_PRINT_TYPE_ACCEL]
description: SET_VELOCITY_LIMIT ACCEL=5000 for print moves
gcode:
  SET_ACCEL_FOR_TYPE TYPE=Default                  VALUE=5000

  SET_ACCEL_FOR_TYPE TYPE=FirstLayer               VALUE=3000
  SET_ACCEL_FOR_TYPE TYPE=Skirt                    VALUE=3000

  SET_ACCEL_FOR_TYPE TYPE=ExternalPerimeter        VALUE=5000
  SET_ACCEL_FOR_TYPE TYPE=ThinWall                 VALUE=5000
  SET_ACCEL_FOR_TYPE TYPE=Perimeter                VALUE=5000
  SET_ACCEL_FOR_TYPE TYPE=OverhangPerimeter        VALUE=5000
  SET_ACCEL_FOR_TYPE TYPE=TopSolidInfill           VALUE=5000
  SET_ACCEL_FOR_TYPE TYPE=GapFill                  VALUE=5000

  SET_ACCEL_FOR_TYPE TYPE=BridgeInfill             VALUE=5000
  SET_ACCEL_FOR_TYPE TYPE=SolidInfill              VALUE=7000
  SET_ACCEL_FOR_TYPE TYPE=InternalInfill           VALUE=7000

  SET_ACCEL_FOR_TYPE TYPE=SupportMaterial          VALUE=5000
  SET_ACCEL_FOR_TYPE TYPE=SupportMaterialInterface VALUE=5000
  SET_ACCEL_FOR_TYPE TYPE=WipeTower                VALUE=5000

  M118 SUPER accel, default 5000


[gcode_macro CONFIGURE_TURTLE_PRINT_TYPE_ACCEL]
description: SET_VELOCITY_LIMIT ACCEL=500 for print moves
gcode:
  SET_ACCEL_FOR_TYPE TYPE=Default                  VALUE=500

  SET_ACCEL_FOR_TYPE TYPE=FirstLayer               VALUE=500
  SET_ACCEL_FOR_TYPE TYPE=Skirt                    VALUE=500

  SET_ACCEL_FOR_TYPE TYPE=ExternalPerimeter        VALUE=500
  SET_ACCEL_FOR_TYPE TYPE=ThinWall                 VALUE=500
  SET_ACCEL_FOR_TYPE TYPE=Perimeter                VALUE=500
  SET_ACCEL_FOR_TYPE TYPE=OverhangPerimeter        VALUE=500
  SET_ACCEL_FOR_TYPE TYPE=TopSolidInfill           VALUE=500
  SET_ACCEL_FOR_TYPE TYPE=GapFill                  VALUE=500

  SET_ACCEL_FOR_TYPE TYPE=BridgeInfill             VALUE=500
  SET_ACCEL_FOR_TYPE TYPE=SolidInfill              VALUE=500
  SET_ACCEL_FOR_TYPE TYPE=InternalInfill           VALUE=500

  SET_ACCEL_FOR_TYPE TYPE=SupportMaterial          VALUE=500
  SET_ACCEL_FOR_TYPE TYPE=SupportMaterialInterface VALUE=500
  SET_ACCEL_FOR_TYPE TYPE=WipeTower                VALUE=500

  M118 TURTLE accel, default 500

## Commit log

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2021-07-06 fix orientation
    [lgx-chain-anchor-low.stl]
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2021-07-23 add lgx notes to save people from fscking up their stuff like I did
    [afterburner.cfg]
2021-07-23 disable x/y steppers the klipper way, since any M18 command seems to disable z as well raise back independently to help when qgl won't work because of back sag
    [axes.cfg, macros.cfg]
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2021-09-05 adjust based on new input shaper and pressure advance tuning
    [adxl.cfg, afterburner.cfg, printer.cfg]
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2021-09-17 pass bed and hotend temp in so cura doesn't warm up before we can switch on the exhaust fan...
    [print.cfg]
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2021-09-26 shuffle BED_MESH_CLEAR so that the prior mesh doesn't affect QGL https://discord.com/channels/460117602945990666/472450547534921729/891655322001891348
    [gantry.cfg, util.cfg]
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2021-09-27 break apart SET_PRINT_MOVE_ACCEL into a more configurable format
    [PRINT_TYPE_ACCEL.cfg, accel.cfg, macros.cfg]
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2021-11-09 add SKIP_MESH
    [filament.cfg, init.cfg, macros.cfg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]
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2021-11-11 add ATC Semitec 104NT-4-R025H42G shuffle pid tuning to specific hotend config
    [104NT-4.cfg, extras.cfg, mosquito.cfg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]
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2021-12-07 update tuning
    also, fix axes so the graph reads properly
    [adxl.cfg]
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2022-01-08 shuffle so we can swap inductive probe for klicky at any time
    [omron.cfg]
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2022-01-08 whoops - delayed_gcode doesn't get a description
    [bofa.cfg, init.cfg, util.cfg]
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2022-01-09 get btt sensor actually working without tripping 10 times per print
    [btt_filament_runout.cfg]
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2022-01-13 add SKIP_CHAMBER_WAIT
    [init.cfg, mesh.cfg, preheat.cfg]
2022-01-13 remove CLEAR_CHAMBER_WAIT since it doesn't work
    [preheat.cfg]
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2022-01-21 add ability to skip filament runout sensor for duration of print
    [filament.cfg, init.cfg]
2022-01-29 set nozzle_diameter to 1mm to keep klipper from limiting flow set in the slicer
    [dragon-hf.cfg, dragon.cfg, mosquito.cfg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]
2022-01-29 correct default accel configs
    [printer.cfg]
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2022-02-02 fix tyop
    [toolhead.cfg]
2022-02-02 add bofa skip
    [bofa.cfg, cleanup.cfg, init.cfg]
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2022-02-16 update to latest klipper recommendations prep for stealthburner
    [macros.cfg, neopixel.cfg, toolhead.cfg]
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2022-02-19 fix menu shuffle
    [disable.cfg, menu.cfg]
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2022-03-02 replace STATUS_PRINTING
    [rainbow.cfg]
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2022-03-10 make sure RESUME uses the current target temperature
    [print.cfg]
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2022-03-12 add helpers for verify switch and nozzle positions
    [z_calibration.cfg]
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2022-03-18 fix display
    [display_z.cfg]
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2022-03-20 remove display_z in favor of better menu option
    [display_z.cfg, klicky.cfg]
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2022-03-20 correct dock location
    [klicky-variables.cfg]
2022-03-20 add skip to z sanity check
    [init.cfg, z_calibration.cfg]
2022-03-20 fix default state on skip macros
    [bofa.cfg, filament.cfg, mesh.cfg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]
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2022-03-21 more better skip processing
    [bofa.cfg, cleanup.cfg, filament.cfg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]
2022-03-21 nozzle swap
    [dragon-hf.cfg]
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2022-03-29 add nozzle swap macros
    [nozzles.cfg, variables.cfg]
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2022-03-30 add skips separate out sanity check
    [klicky.cfg, probe.cfg, z_calibration.cfg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]
2022-03-30 reset timeout at end of print
    [cleanup.cfg]
2022-03-30 fix skips
    [mesh.cfg]
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2022-03-30 add skips
    [preheat.cfg]
2022-03-30 add skips shuffle PRINT_START
    [print.cfg]
2022-03-30 replace all action_respond_info calls with M118 to maintain execution order
    [PRINT_TYPE_ACCEL.cfg, TEST_SPEED.cfg, bofa.cfg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]
2022-03-30 make sure both M117 and M118 make it to klippy.log
    [overrides.cfg]
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2022-03-31 skip nozzle temp on soak
    [preheat.cfg]
2022-04-04 reduce idle timeout during probe moves to protect against cooking the klicky
    [klicky-macros.cfg, z_calibration.cfg]
2022-04-04 shuffle preflight order a bit reduce idle timeout during preflight
    [print.cfg]
2022-04-04 add ERROR_NOTIFY
    [notify.cfg, printer.cfg]
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2022-04-05 fix error notify
    [notify.cfg]
2022-04-05 add SKIP_QGL
    [gantry.cfg, mesh.cfg]
2022-04-05 separate out qgl so that mesh doesn't apply to auto z
    honestly not sure if this matters at all, given that the z endstop
    is outside the mesh bounds...
    [print.cfg]
2022-04-05 reset skip qgl
    [util.cfg]
2022-04-05 try some tighter tolerances
    [bed.cfg]
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2022-04-06 correct nozzle size :/
    [nozzles.cfg]
2022-04-06 wait for chamber to reach temperature before turning on the exhaust back to preheating the toolhead, as it shifts. duh.
    [print.cfg]
2022-04-10 fix another race condition :/
    [notify.cfg, printer.cfg]
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2022-04-11 reset to fast accel at end, manage accels from slicer
    [cleanup.cfg]
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2022-04-14 remove filament overrides - you can do it in the slicer :)
    [filament.cfg]
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2022-04-16 shorten the path a bit
    [toolhead.cfg]
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2022-04-25 add bevel, fix model
    [z-drive-main_side-inserts.stl]
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2022-04-29 add FINE accel config reset accelerations at the end of a print to undo new SS M204 inserts
    [accel.cfg, cleanup.cfg, init.cfg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]
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2022-04-29 add some input shaper swap routines
    [adxl.cfg]
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2022-05-03 skip sanity check on menu probe - it's always used in isolation so doesn't need to abort a print in progress
    [probe.cfg]
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2022-05-04 wait a few seconds for the rainbow to stop
    [cleanup.cfg]
2022-05-04 shorten idle timeout only during an actual print
    [klicky-macros.cfg, print.cfg, z_calibration.cfg]
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2022-05-08 ugh, jinja2 only evaluates once, so we need a workaround...
    [preheat.cfg]
2022-05-08 add some useful skips
    [preheat.cfg, print.cfg]
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2022-05-21 add new cw2 model, which can be printed as a whole piece shuffle directories
    [sb-lgx-front-cw1.stl, sb-lgx-front-cw2-v5.stl, sb-lgx-front-cw2.stl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]
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2022-06-25 tidy adxl stuff fix menu
    [adxl.cfg, pa_is.cfg, skips.cfg]
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2022-06-29 ugh, not sure how I missed this for so long...
    [print.cfg]
2022-07-04 assume I'll be working on the printer a bit while testing resonances...
    [pa_is.cfg]
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2022-07-15 add some lcd status messages since the button is less responsive nowadays...
    [mesh.cfg, preheat.cfg, print.cfg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]
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2022-07-15 restore shaper on init, just so I can see it in the console
    [init.cfg]
2022-07-15 ran into a strange condition where it tried to extrude 50.01mm of filament and it was failing. so don't bump so close to the limit
    [filament.cfg]
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2022-08-23 add ability to skip extruder cooldown on runout
    [filament.cfg, util.cfg]
2022-08-23 remove gcode state save/restore - it also re-extrudes and negates what I'm trying to do...
    [toolhead.cfg]
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2022-09-11 add ercf extruder fixme
2022-10-11 klipper doesn't like numbers in the middle of macro names, apparently
    [tc.cfg]
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2022-11-07 remove clog notification, since it doesn't matter adjust tip values
    [ercf_software.cfg]
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2022-11-09 separate out error routine so the pause check is accurate (the pre-evaluation stuff always gets me)
    [ercf.cfg, ercf_software.cfg, tool.cfg]
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2022-11-18 fix multi-extruder settings
2022-11-18 add standalone tip formation macro, for times when the ercf isn't loaded
    [FORM_TIP.cfg, util.cfg]
2022-11-18 tidy pause to keep my frustration level down when the ercf isn't cooperating...
    [print.cfg]
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2022-11-18 menu fixes
    [ercf.cfg, load.cfg, preheat.cfg]
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2022-11-19 fix menu load
    [ercf.cfg, menu.cfg]
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2022-11-22 add SKIP_ERCF_PAUSE
    [ercf.cfg]
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2022-11-23 add missing custom macros
    [custom.cfg, effects.cfg, led_effects.cfg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]
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2022-11-28 offset filament ingress and egress, based on feedback from @ningj V2.2726 - thanks!
    [buffer-screen-a.stl, buffer-top-ecas+ecas.stl, buffer-top-ecas+magnet.stl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]
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2022-12-11 fix exhaust fan
    [print.cfg]
2022-12-11 fix unlock
    [ercf.cfg]
2022-12-12 restart using your phone or computer and you won't cancel a print 36 hours in...
    [restart.cfg]
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2022-12-13 don't restore pressure advance until we're ready to roll plus other tweaks
    [tool.cfg]
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2022-12-28 swap pins
    [ercf_hardware-ezbrd.cfg]
2022-12-29 fix broken gcode redefines
    [overrides.cfg]
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2023-01-04 set RESUME etemp up front so it can be referenced at any time other minor tweaks
    [print.cfg]
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2023-01-12 add correct model
    [servo-arm-dfh.stl]
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2023-02-04 add optional brush after load so slicer can brush before purge if I want...
    [tool.cfg]
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2023-02-12 tidy calibration shortcuts
    [calibration.cfg]
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2023-02-14 swap to rapido
    [toolhead.cfg]
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2023-02-14 notify on some errors
    [nozzles.cfg]
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2023-02-18 add home_position_to_nozzle variable to use for hotend swaps...
    [FORM_TIP.cfg]
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2023-02-20 don't brush if we're not actually swapping filaments...
    [tool.cfg]
2023-02-20 turn off heaters again at end (in case ercf turned them on to eject)
    [print.cfg]
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2023-02-27 fix heatset size
    [frame-9.stl]
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2023-02-28 no need to save all that state if you only care about the end...
    [TUNING_TOWER.cfg]
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2023-03-02 add sd card error trap
    [printer.cfg]
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2023-03-08 move purge line down so it doesn't overlap with the wipe tower skirt
    [print.cfg]
2023-03-08 add purge option to BRUSH just in case I need an extra purge during filament swaps
    [toolhead.cfg]
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2023-03-08 add sensor_to_nozzle and extruder_to_nozzle... even though I can't set them to zero (yet)
    [ercf_parameters.cfg]
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2023-03-20 tweak brush logic on swaps
    [tool.cfg]
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2023-03-31 add purge line skip
    [print.cfg]
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2023-03-31 fix incorrect macro call
    [probe.cfg]
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2023-04-06 escape message characters so they don't blow things up refactor error notify code
    [shell.cfg]
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2023-04-06 rework CHAMBER_WAIT so that it now actually starts convection like I wanted the result of the new behavior is a shorter "soak" time that really isn't a soak, add a minimum chamber soak if we start at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
    [preheat.cfg, print.cfg]
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2023-04-06 rework home+park logic a bit
    [ercf.cfg, tool.cfg]
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2023-04-10 update extender to use magnets on both sides. much more friendly interface.
    [ecas-to-magnet-end.stl, extender-12.stl, extender-6.stl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]
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2023-04-11 tidy error messaging
    [shell.cfg, util.cfg]
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2023-04-12 fix X117 (finally)!
    [overrides.cfg]
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2023-04-16 use error messaging
    [util.cfg]
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2023-05-25 add temperature restore to tap shuffle lesser used tap break in routines
    [extra.cfg, tap.cfg]
2023-05-25 cleanup on error
    [util.cfg]
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2023-05-29 remove purge skip - it didn't help anyway
    [tap.cfg]
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2023-05-30 home z when skipping mesh, now that we're using tap
    [mesh.cfg]
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2023-06-03 move pt1000 to the sf dragon make sure the hf dragon blows up if I try to use it
    [dragon-hf.cfg, dragon-sf.cfg]
2023-06-05 add short tap belt cover
    [short_tap_belt_cover_r8_x2.stl]
2023-06-09 extend faulty regions to prevent bumping against the brush
    [bed.cfg]
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2023-06-15 step one of removing hotend as a nozzle key if you always copy the values, there's no point...
    [nozzles.cfg]
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2023-07-03 rename hotend models so people know they can split the colors out...
    [half-dragon-multicolor.stl, half-rapido-multicolor.stl]
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2023-07-03 separate out intial tap offset so it can be called directly as a restore option
    [tap.cfg]
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2023-07-09 reset pause on toolchange at end of print
    [ercf.cfg]
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2023-07-09 add required checks to mesh generation before skipping...
    [mesh.cfg]
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2023-09-01 reset motor currents
    [axes.cfg]
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2023-09-15 swap out dead hotend fan port
    [toolhead.cfg]
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2023-09-15 fix broken hop
    [toolhead.cfg]
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2023-10-03 cancel on sd error...
    [printer.cfg]
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2023-10-10 always reset everything at print start
    [print.cfg]
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2023-10-31 add SKIP_BRUSH
    [toolhead.cfg, util.cfg]
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2023-11-27 add preload shortcuts
    [tool.cfg]
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2023-12-30 fix cut and paste
    [preheat.cfg]
2023-12-30 add shaketune vibrations macro
    [pa_is.cfg]
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2024-03-28 add mandatory soak /after/ chamber reaches temp. otherwise it's not a soak. duh.
    [preheat.cfg]
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2024-12-09 lower min temp... probably to keep from ping-ponging around for lower temps, but honestly I forget why
    [ercf_parameters.cfg]
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2025-01-31 add in solid (aka "filled") versions of hotend backs
    the thought here is that the solid versions are less likely to
    compress when hulked down, and therefore the printhead is
    less likely to tilt out of square relative to the print bed
    [sb-official-dragon_filled.stl, sb-official-rapido_filled.stl]
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2025-05-22 add missing variable
    [preheat.cfg]
2025-05-22 don't turn off heaters on cancel if SKIP_COOLDOWN
    [print.cfg]
2025-05-22 FILAMENT_LOAD: skip everything if the temp is too low. also, go slower at lower temps
    [filament.cfg]
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2025-05-22 add NOTE_FAN/RESTORE_FAN add ability to pause on a specific layer or the next layer
    [util.cfg]
2025-05-22 add NOTIFY_AFTER_MESH/CLEAR_NOTIFY_AFTER_MESH enforce zero fan before generating a mesh, restore after mesh complete
    [mesh.cfg]
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
